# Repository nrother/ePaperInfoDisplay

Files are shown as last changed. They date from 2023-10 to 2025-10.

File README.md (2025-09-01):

# ePaper Info Display

A wireless, battery-powered ePaper Display that shows you important information at a glance.
Inspired by [a similiar project](https://spritesmods.com/?art=einkdisplay) by spritesmods.

A [7.4' ePaper Display from PervasiveDisplays](https://www.pervasivedisplays.com/product/7-4-e-ink-displays/) is used as the display.
It is powered by ESP32-C3 WiFi-enabled microcontroller.
The microcontroller wakes up every 24 hours and updates the e-paper display with an 800x480 image downloaded from a server.
On the server side, a Python script generates the image, showing a calendar, the weather forecast, and the next appointments.

This repository contains the hardware, firmware and software for the project.

## Hardware

The `hardware/` folder contains all schematics and PCB layouts in KiCAD format.

### Changelog

#### Rev. 3

- Fixed swapped USB DP+/-, USB usable again
- Fixed swapped labels USR1/USR2
- Add resistor divider for VBAT_SENSE to avoid excessive voltage on GPIO pin
- WAKEUP button changed to BOOT (connected to GPIO9)
- VBAT_SENSE moved to GPIO4 which has a usable ADC
- GPIO association of some signals changed to avoid issues strapping pins:
	- LED1 now on GPIO5
	- LED2 now on GPIO6
	- /BUSY now on GPIO7
	- /PWR_EN now on GPIO8

##### Known issues

None

#### Rev.2 (only usable with fixes)
- Use bottom-connect FPC connector
- Mirror some parts of the layout

##### Known issues
- USB DP+/- is switched
- #BUSY of Display is connected to GPIO9, which causes the chip to enter the Bootloader every time
- VBAT_SENSE is on ADC2_CH0 which is not usable when WiFi is active
- Labels USR1/USR2 are switched
- GPIO8 and GPIO2 (which are strapping pins) are used otherwise
- The WAKEUP button is useless (one can just use RESET), but a boot button would have been nice

#### Rev.1 (broken)
- First revision

##### Known issues
- Orientation/Location of ePaper FPC connector is wrong

## Firmware

The firmware can be found in the `firmware/` folder.
It is based on [ESPHome](https://esphome.io/).

To get started:
```shell
cd firmware/
python3 -m venv .venv
. .venv/bin/activate
pip install -r requirements.txt
cp secrets.example.yaml secrets.yaml
vim secrets.yaml
esphome compile epaperinfodisplay.yaml
esphome upload epaperinfodisplay.yaml
```

There is a ESPHome-compatible custom component for the e-paper display from Pervasive Displays in `esphome/`.
This might also be useful outside this project.

## Software

The host software is writting in Python using [Flask](https://flask.palletsprojects.com/en/stable/).
It must run on some kind of server, like a Raspberry Pi or a NAS.

To get started:
```shell
cd software/
python3 -m venv .venv
. .venv/bin/activate
pip install -r requirements.txt
cp config.example.yaml config.yaml
vim config.yaml
flask run --host 0.0.0.0 # make accessible from outside localhost
```

Weather data is fetched from [OpenMeteo](https://open-meteo.com/).
For this to work you need to specify your location in the `config.yaml` file.
Calendar appointments are fetched from a CalDAV server.
The example configuration contains the correct path for [Baïkal](https://sabre.io/baikal/), but any kind of CalDAV server should work.
You might need to find out the correct path for your server.

## License

MIT

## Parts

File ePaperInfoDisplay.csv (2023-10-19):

ID | Bezeichner | Footprint | Stückzahl | Bezeichnung | Anbieter und Referenz
1 | J2 | USB_C_Receptacle_GCT_USB4105-xx-A_16P_TopMnt_Horizontal | 1 | USB_C_Receptacle_USB2.0 | 640-USB4105-GF-A-120
2 | SW2,SW1 | SW_PUSH_6mm | 2 | SW_Push | 611-PTS645SH432
3 | C4 | C_0805_2012Metric_Pad1.18x1.45mm_HandSolder | 1 | 2.2uF | 187-CL21A225KAFNNNG
4 | D5,D1,D6 | LED_0805_2012Metric_Pad1.15x1.40mm_HandSolder | 3 | LED | 710-150080RS75000
5 | L1 | L_7.3x7.3_H4.5 | 1 | 47uH | 871-B82472G6473M000
6 | C11 | C_0805_2012Metric_Pad1.18x1.45mm_HandSolder | 1 | 0.47uF/25V | 187-CL21A475KAQNNNG
7 | R11,R4,R12 | R_0805_2012Metric_Pad1.20x1.40mm_HandSolder | 3 | 470R | IMS
8 | D7,D2,D4,D3 | D_SOD-123F | 4 | D_Schottky | 755-RB161MM-20TR
9 | C16 | C_0805_2012Metric_Pad1.18x1.45mm_HandSolder | 1 | 100nF | IMS
10 | C2,C1,C10,C13 | C_0805_2012Metric_Pad1.18x1.45mm_HandSolder | 4 | 4.7uF/25V | 187-CL21A475KAQNNNE
11 | Q3,Q2 | SOT-323_SC-70_Handsoldering | 2 | Q_PMOS_GSD | 942-IRLML6402TRPBF
12 | C12,C14,C9,C8,C3,C7,C5,C18,C15 | C_0805_2012Metric_Pad1.18x1.45mm_HandSolder | 9 | 1uF/25V | 187-CL21B105KAFNFNE
13 | C6 | C_0805_2012Metric_Pad1.18x1.45mm_HandSolder | 1 | 470pF | IMS
14 | R6,R9,R10,R7,R8 | R_0805_2012Metric_Pad1.20x1.40mm_HandSolder | 5 | 10K | IMS
15 | U2 | SOT-23-5_HandSoldering | 1 | MIC5219-3.3YM5 | 998-MIC5219-3.3YM5TR
16 | C17 | C_0805_2012Metric_Pad1.18x1.45mm_HandSolder | 1 | 100nF/16V | IMS
17 | 1 | ESP32-C3-WROOM-02 | 1 | ESP32-C3-WROOM-02 | 356-ESP32C3WROOM02N4
18 | R3 | R_0805_2012Metric_Pad1.20x1.40mm_HandSolder | 1 | 2k | 603-RC0805FR-072KP
19 | U3 | TE_2-1734839-4_1x24-1MP_P0.5mm_Horizontal | 1 | ePD_iTC | 571-2-1734839-4
20 | R5 | R_0805_2012Metric_Pad1.20x1.40mm_HandSolder | 1 | 0R | IMS
21 | R2,R1 | R_0805_2012Metric_Pad1.20x1.40mm_HandSolder | 2 | 5.1k | 603-RT0805FRE135K1L
22 | U1 | SOT-23-5_HandSoldering | 1 | MCP73831-2-OT | 579-MCP73831T-2ACIOT
23 | R13 | R_0805_2012Metric_Pad1.20x1.40mm_HandSolder | 1 | 100K | IMS
24 | Q1 | SOT-323_SC-70_Handsoldering | 1 | Q_NMOS_GSD | 78-SI1308EDL-T1-GE3
25 |  | Pogo Pins | 2 |  | 575-907811
26 |  | ePaper
 |  | Battery
 |  | USB C-A Kabel

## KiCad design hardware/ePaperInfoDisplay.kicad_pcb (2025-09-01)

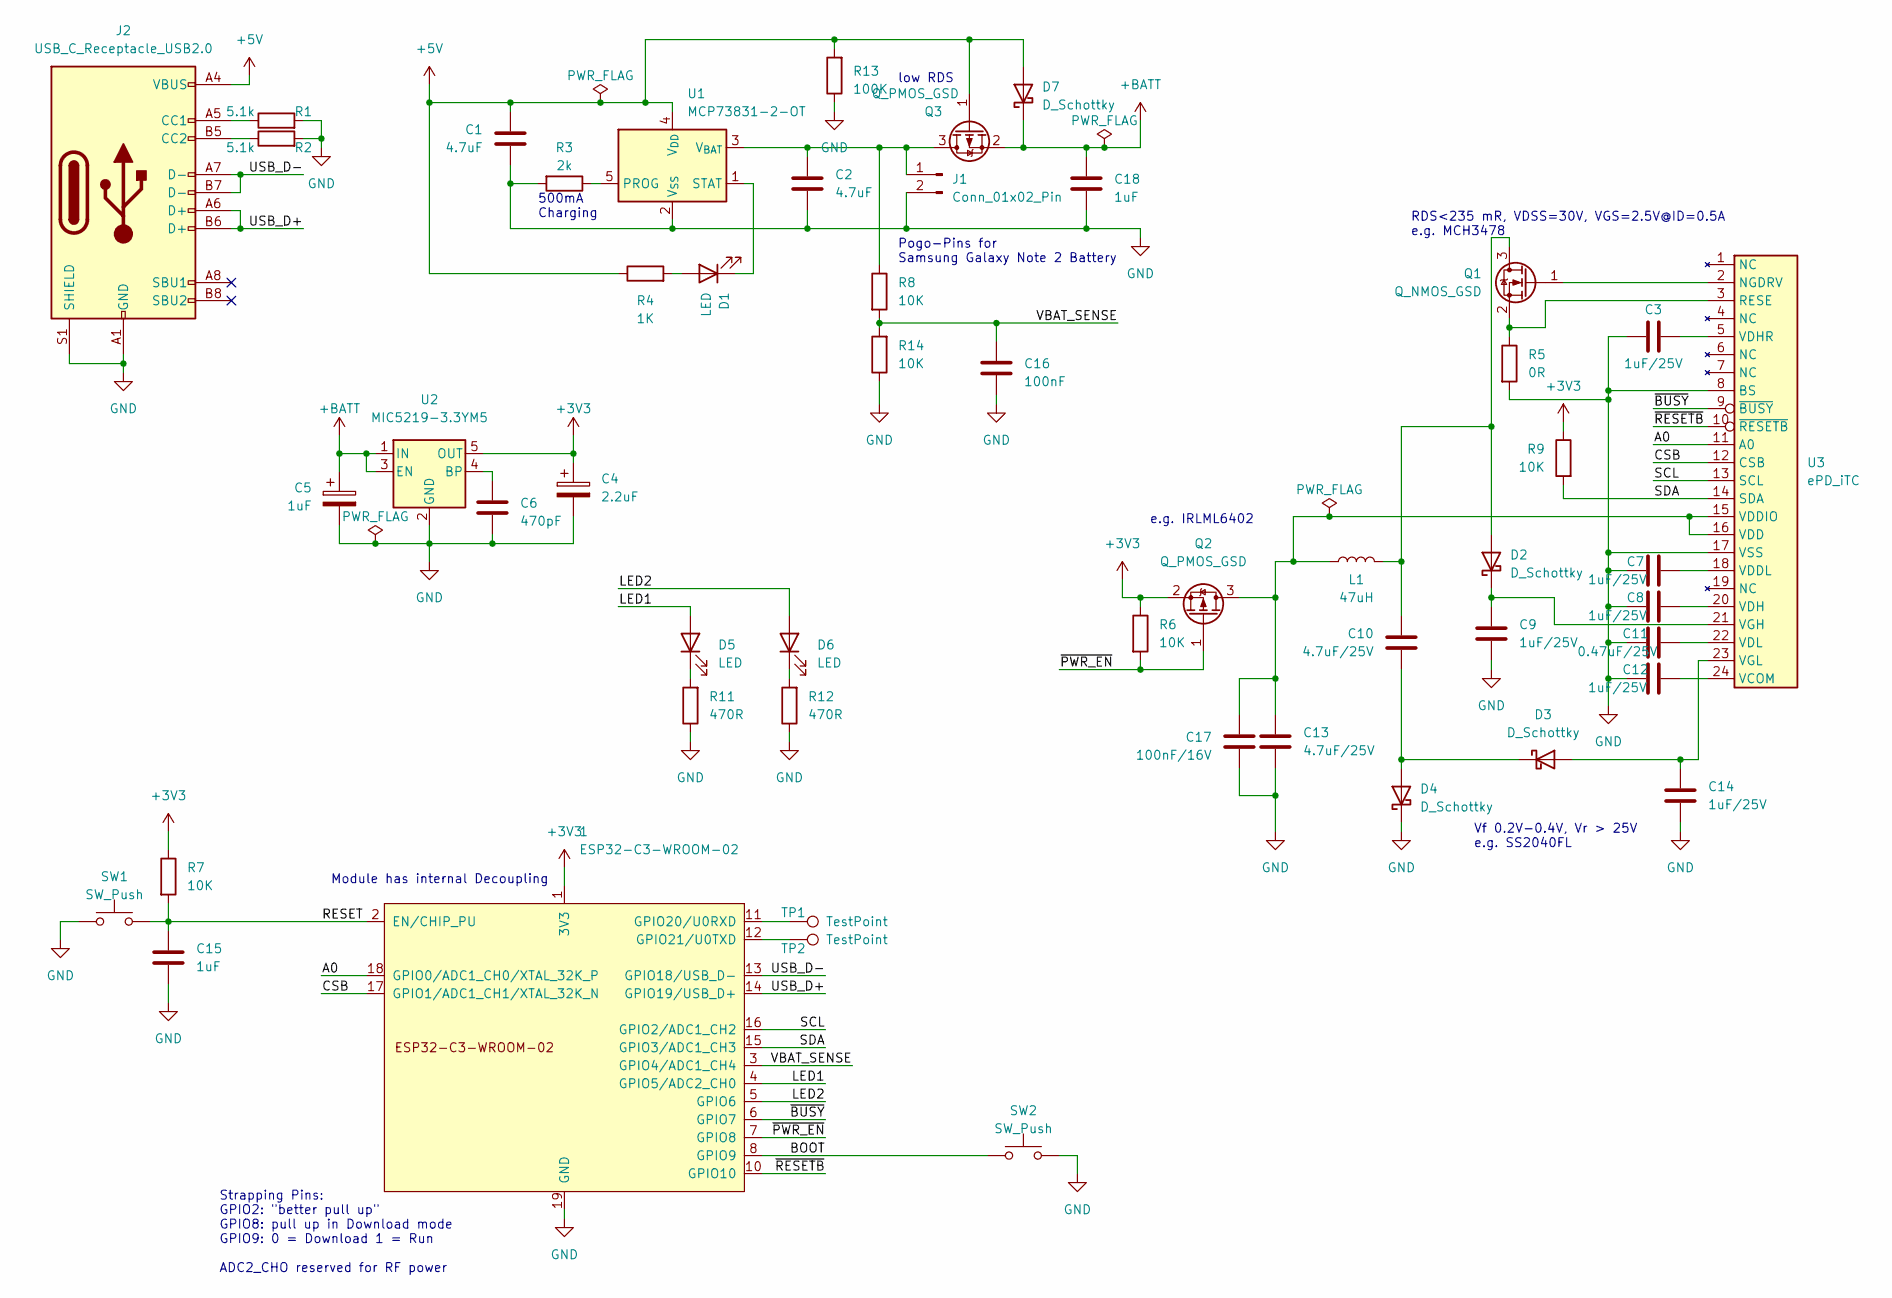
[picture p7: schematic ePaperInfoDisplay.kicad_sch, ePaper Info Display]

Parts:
1: ESP32-C3-WROOM-02
C1, C2: 4.7uF; C_0805_2012Metric_Pad1.18x1.45mm_HandSolder
C3, C7, C8, C9, C12, C14: 1uF/25V; C_0805_2012Metric_Pad1.18x1.45mm_HandSolder
C4: 2.2uF; C_0805_2012Metric_Pad1.18x1.45mm_HandSolder
C5, C15, C18: 1uF; C_0805_2012Metric_Pad1.18x1.45mm_HandSolder
C6: 470pF; C_0805_2012Metric_Pad1.18x1.45mm_HandSolder
C10, C13: 4.7uF/25V; C_0805_2012Metric_Pad1.18x1.45mm_HandSolder
C11: 0.47uF/25V; C_0805_2012Metric_Pad1.18x1.45mm_HandSolder
C16: 100nF; C_0805_2012Metric_Pad1.18x1.45mm_HandSolder
C17: 100nF/16V; C_0805_2012Metric_Pad1.18x1.45mm_HandSolder
D1, D5, D6: LED; LED_0805_2012Metric_Pad1.15x1.40mm_HandSolder
D2, D3, D4, D7: D_Schottky; D_SOD-123F
J1: Conn_01x02_Pin; PinHeader_1x02_P2.54mm_Vertical
J2: USB_C_Receptacle_USB2.0; USB_C_Receptacle_GCT_USB4105-xx-A_16P_TopMnt_Horizontal
L1: 47uH; L_7.3x7.3_H4.5
Q1: Q_NMOS_GSD; SOT-323_SC-70_Handsoldering
Q2, Q3: Q_PMOS_GSD; SOT-323_SC-70_Handsoldering
R1, R2: 5.1k; R_0805_2012Metric_Pad1.20x1.40mm_HandSolder
R3: 2k; R_0805_2012Metric_Pad1.20x1.40mm_HandSolder
R4: 1K; R_0805_2012Metric_Pad1.20x1.40mm_HandSolder
R5: 0R; R_0805_2012Metric_Pad1.20x1.40mm_HandSolder
R6, R7, R8, R9, R14: 10K; R_0805_2012Metric_Pad1.20x1.40mm_HandSolder
R11, R12: 470R; R_0805_2012Metric_Pad1.20x1.40mm_HandSolder
R13: 100K; R_0805_2012Metric_Pad1.20x1.40mm_HandSolder
SW1, SW2: SW_Push; SW_PUSH_6mm
TP1, TP2: TestPoint; TestPoint_Pad_D1.0mm
U1: MCP73831-2-OT; SOT-23-5_HandSoldering
U2: MIC5219-3.3YM5; SOT-23-5_HandSoldering
U3: ePD_iTC; TE_2-1734592-4_1x24-1MP_P0.5mm_Horizontal

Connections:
+3V3: 1.1 (3V3), C4.1, Q2.2 (S), R6.1, R7.1, R9.1, U2.5 (OUT)
+5V: C1.1, D7.2 (A), J2.A4 (VBUS), J2.A9 (VBUS), J2.B4 (VBUS), J2.B9 (VBUS), Q3.1 (G), R4.1, R13.2, U1.4 (V_{DD})
+BATT: C5.1, C18.1, D7.1 (K), Q3.2 (S), U2.1 (IN), U2.3 (EN)
/A0: 1.18 (GPIO0/ADC1_CH0/XTAL_32K_P), U3.11 (A0)
/BOOT: 1.8 (GPIO9), SW2.2
/CSB: 1.17 (GPIO1/ADC1_CH1/XTAL_32K_N), U3.12 (CSB)
/LED1: 1.4 (GPIO5/ADC2_CH0), D5.2 (A)
/LED2: 1.5 (GPIO6), D6.2 (A)
/RESET: 1.2 (EN/CHIP_PU), C15.1, R7.2, SW1.2
/SCL: 1.16 (GPIO2/ADC1_CH2), U3.13 (SCL)
/SDA: 1.15 (GPIO3/ADC1_CH3), R9.2, U3.14 (SDA)
/USB_D+: 1.14 (GPIO19/USB_D+), J2.A6 (D+), J2.B6 (D+)
/USB_D-: 1.13 (GPIO18/USB_D-), J2.A7 (D-), J2.B7 (D-)
/VBAT_SENSE: 1.3 (GPIO4/ADC1_CH4), C16.1, R8.2, R14.2
/~BUSY: 1.6 (GPIO7), U3.9 (~BUSY)
/~PWR_EN: 1.7 (GPIO8), Q2.1 (G), R6.2
/~RESETB: 1.10 (GPIO10), U3.10 (~RESETB)
GND: 1.9 (GND), 1.19 (GND), C1.2, C2.2, C3.1, C4.2, C5.2, C6.2, C7.1, C8.1, C9.2, C11.1, C12.1, C13.2, C14.2, C15.2, C16.2, C17.2, C18.2, D4.1 (K), J1.2, J2.A1 (GND), J2.A12 (GND), J2.B1 (GND), J2.B12 (GND), J2.S1 (SHIELD), R1.2, R2.2, R3.2, R5.2, R11.1, R12.1, R13.1, R14.1, SW1.1, SW2.1, U1.2 (V_{SS}), U2.2 (GND), U3.8 (BS), U3.17 (VSS)
unnamed: 1.11 (GPIO20/U0RXD), TP1.1
unnamed: 1.12 (GPIO21/U0TXD), TP2.1
unnamed: D1.2 (A), R4.2
unnamed: D1.1 (K), U1.1 (STAT)
unnamed: C10.1, D2.2 (A), L1.2, Q1.3 (D)
unnamed: C9.1, D2.1 (K), U3.21 (VGH)
unnamed: C14.1, D3.2 (A), U3.23 (VGL)
unnamed: C10.2, D3.1 (K), D4.2 (A)
unnamed: D5.1 (K), R11.2
unnamed: D6.1 (K), R12.2
unnamed: C2.1, J1.1, Q3.3 (D), R8.1, U1.3 (V_{BAT})
unnamed: J2.A5 (CC1), R1.1
unnamed: J2.B5 (CC2), R2.1
unnamed: Q1.1 (G), U3.2 (NGDRV)
unnamed: Q1.2 (S), R5.1, U3.3 (RESE)
unnamed: C13.1, C17.1, L1.1, Q2.3 (D), U3.15 (VDDIO), U3.16 (VDD)
unnamed: R3.1, U1.5 (PROG)
unnamed: C6.1, U2.4 (BP)
unnamed: C12.2, U3.24 (VCOM)
unnamed: C7.2, U3.18 (VDDL)
unnamed: C8.2, U3.20 (VDH)
unnamed: C3.2, U3.5 (VDHR)
unnamed: C11.2, U3.22 (VDL)

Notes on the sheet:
500mA Charging
Module has internal Decoupling
low RDS
Pogo-Pins for Samsung Galaxy Note 2 Battery
e.g. IRLML6402
RDS<235 mR, VDSS=30V, VGS=2.5V@ID=0.5A e.g. MCH3478
Vf 0.2V-0.4V, Vr > 25V e.g. SS2040FL
Strapping Pins: GPIO2: "better pull up" GPIO8: pull up in Download mode GPIO9: 0 = Download 1 = Run ADC2_CHO reserved for RF power

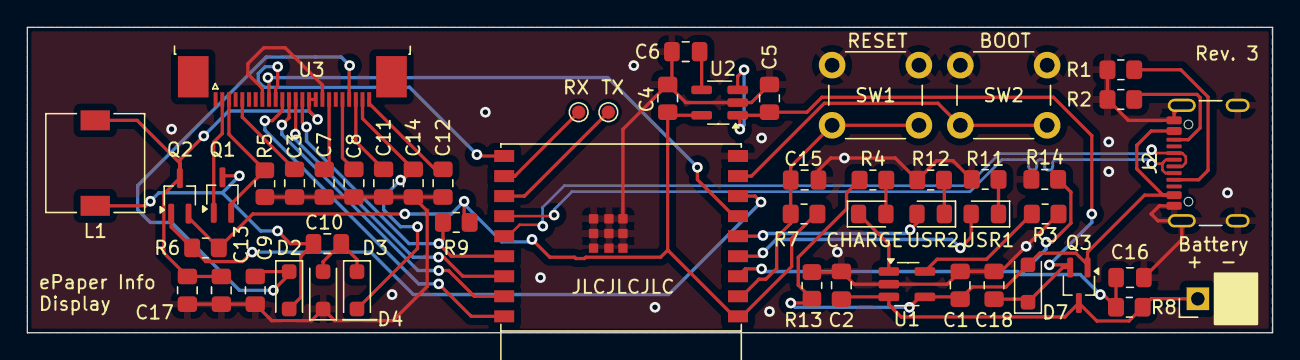
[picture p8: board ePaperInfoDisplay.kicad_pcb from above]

Board: 2 copper layers, 93.2 x 22.9 mm, 52 parts (0 on the bottom side), 41 nets.

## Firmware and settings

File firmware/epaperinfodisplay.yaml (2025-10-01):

esphome:
  name: epaperinfodisplay
  on_boot:
    - output.turn_on: led_2

esp32:
  board: esp32-c3-devkitm-1
  framework:
    type: arduino

external_components:
  - source:
      type: local
      path: ../esphome/components/

# Enable logging
logger:

# Enable Home Assistant API
#api:
#  password: ""

ota:
  - platform: esphome
    password: !secret ota_password

wifi:
  ssid: !secret wifi_ssid
  password: !secret wifi_password
  fast_connect: true # connect without scanning first, should save time

  # Enable fallback hotspot (captive portal) in case wifi connection fails
  ap:
    password: !secret fallback_ap_password

  on_connect:
    - output.turn_on: led_1
    - script.execute: download_image_script
  on_disconnect:
    - output.turn_off: led_1

captive_portal:

output:
  - platform: gpio
    pin: 7
    id: led_1
  - platform: gpio
    pin: 8
    id: led_2

spi:
  clk_pin:
    number: 2
    ignore_strapping_warning: true
  mosi_pin: 3

globals:
  - id: image_download_ok
    type: 'bool'
    restore_value: no
    initial_value: 'false'

font:
  - file: "gfonts://Roboto"
    id: roboto_20
    size: 20

display:
  id: epaper
  platform: pervasive_displays_epaper
  update_interval: never # update is explicity called
  reset_pin: 10
  busy_pin: 4
  enable_pin: 6
  model: "7.41in"
  dc_pin: 0
  cs_pin: 1
  rotation: 270°
  lambda: |-
    if (id(image_download_ok)) {
      //draw only the image
      it.image(0, 0, id(frame_image), COLOR_OFF, COLOR_ON);
    } else {
      //draw error message
      it.fill(COLOR_ON);
      it.print(400, 50, id(roboto_20), COLOR_OFF, TextAlign::CENTER, "Error");
      it.print(400, 100, id(roboto_20), COLOR_OFF, TextAlign::CENTER, "Image Download failed");
    }

online_image:
  - url: !secret image_url
    id: frame_image
    format: PNG
    # request_headers: # Send current battery voltage as header
    #   X-Bat-Voltage: !lambda |-
    #     return id(vcc_sensor).state;
    #placeholder
    type: BINARY
    buffer_size: 16384 # 16kB buffer, otherwise fails with out of memory
    on_download_finished:
      - globals.set:
          id: image_download_ok
          value: 'true'
      - script.execute: update_display_script
    on_error:
      - globals.set:
          id: image_download_ok
          value: 'false'
      - script.execute: update_display_script

http_request: # required by online_image
  verify_ssl: false #not supported on the Arduino framework

deep_sleep:
  id: my_deep_sleep
  run_duration: 1h # we explicitly enter deep sleep
  sleep_duration: 24h # default

script:
  - id: download_image_script
    then:
      # - component.update: vcc_sensor
      # - logger.log: # DEBUG
      #     format: "VCC is %.1f V"
      #     args: ['id(vcc_sensor).state']
      - component.update: frame_image
      - http_request.get:
          url: !secret wakeup_time_url
          capture_response: true
          on_response:
              - lambda: |-
                  if (response->status_code == 200) {
                      int next = std::stoi(body);
                      id(my_deep_sleep).set_sleep_duration(next * 1000);
                  } else {
                      id(my_deep_sleep).set_sleep_duration(6 * 60 * 60 * 1000); // default to 6h
                  }
          on_error:
              - lambda: |-
                  id(my_deep_sleep).set_sleep_duration(6 * 60 * 60 * 1000); // default to 6h
  - id: update_display_script
    then:
      - wifi.disable: # disable wifi after image was downloaded
      - component.update: epaper
      - script.execute: enter_deepsleep_script
  - id: enter_deepsleep_script
    then:
      - output.turn_off: led_2
      - deep_sleep.enter

# sensor:
#   id: vcc_sensor
#   platform: adc
#   pin: 5 # for testing, the real pin 5 cannot be used when WiFi is active...
#   attenuation: auto
#   update_interval: never

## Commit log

2024-01-06 Add Revision 2
    Use Bottom-connect FPC connector, mirror some parts of the layout
    [ePaperInfoDisplay.kicad_pcb, ePaperInfoDisplay.kicad_sch]
2025-06-26 Move KiCAD files to hardware/
    [ePaperInfoDisplay.kicad_pcb, ePaperInfoDisplay.kicad_sch]
2025-06-26 Update Pervasive Displays driver to follow the app note more closely
2025-06-28 Add spline interpolation to the temperature curve
2025-08-20 Update PCB to KiCAD 9
    [ePaperInfoDisplay.kicad_pcb, ePaperInfoDisplay.kicad_sch]
2025-08-23 Show an error message if image download fails in the firmware
    [epaperinfodisplay.yaml]
2025-09-01 Update hardware to Rev. 3
    Fixed all of the known issues:
    - Fixed swapped USB DP+/-, USB usable again
    - Fixed swapped labels USR1/USR2
    - Add resistor divider for VBAT_SENSE to avoid excessive voltage on GPIO pin
    - WAKEUP button changed to BOOT (connected to GPIO9)
    - VBAT_SENSE moved to GPIO4 which has a usable ADC
    - GPIO association of some signals changed to avoid issues strapping pins:
    - LED1 now on GPIO5
    - LED2 now on GPIO6
    - /BUSY now on GPIO7
    - /PWR_EN now on GPIO8
    [ePaperInfoDisplay.kicad_pcb, ePaperInfoDisplay.kicad_sch]
2026-06-07 Fix scale factor of rain chart
    50mm/h of rain would be *a lot* ;)
2026-10-31 Avoid double-wakeup if the device's clock looses time

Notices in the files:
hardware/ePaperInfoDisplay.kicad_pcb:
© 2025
